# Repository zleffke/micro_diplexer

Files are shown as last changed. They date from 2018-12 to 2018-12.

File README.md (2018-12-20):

# micro_diplexer
KJ4QLP VHF/UHF Diplexer

## Credit where its due!
Inspired by the [KI0AG Micro-Duplexer](http://k0lee.com/duplexer.php) project.  I basically took this design and tweaked some of the values to modify the operating region of the diplexer.

### Note on Terminology - Diplexer vs. Duplexer
Both are three port devices.
A Diplexer is a devices that combines two separate bands (i.e VHF and UHF) into one port.  
A Duplexer is a device that combines two frequencies in the same band onto one port (like the input and output frequencies for a single band repeater).

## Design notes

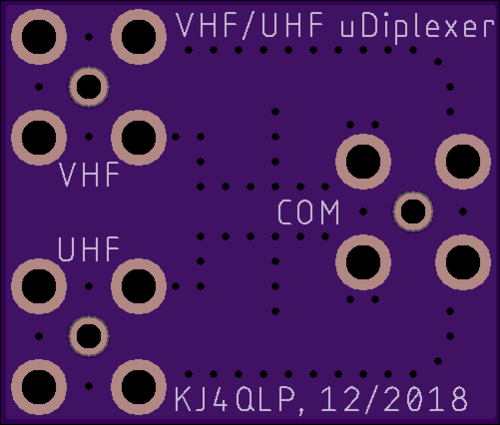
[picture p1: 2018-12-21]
eagle/ver2/rev-/osh_park_bottom.png

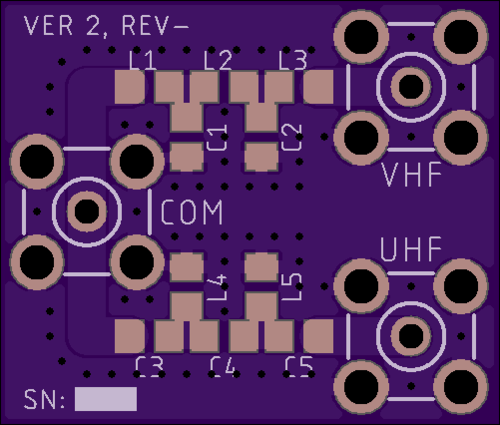
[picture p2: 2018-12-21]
eagle/ver2/rev-/osh_park_top.png

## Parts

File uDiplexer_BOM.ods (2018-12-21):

Supplier | Part # | Description | U/L | Qty | Unit Cost | Total Cost | LINK | Part Ref
Mouser | 603-CC805FRNPO9BN220 | Multilayer Ceramic Capacitors MLCC - SMD/SMT 22pF 50V NPO 1% 0805 | ea | 20 | $0.14 | $2.88 | LINK (https://www.mouser.com/ProductDetail/Yageo/CC0805FRNPO9BN220) | C1, C2
Mouser | 603-CC805CRNPO9BN4R7 | Multilayer Ceramic Capacitors MLCC - SMD/SMT 4.7pF 50V NPO .25pF | ea | 20 | $0.07 | $1.36 | LINK (https://www.mouser.com/ProductDetail/Yageo/CC0805CRNPO9BN4R7) | C3, C5
Mouser | 603-CC805CRNPO9BN3R0 | Multilayer Ceramic Capacitors MLCC - SMD/SMT 3.0pF 50V NPO .25pF | ea | 20 | $0.09 | $1.82 | LINK (https://www.mouser.com/ProductDetail/Yageo/CC0805CRNPO9BN3R0?qs=sGAEpiMZZMs0AnBnWHyRQMmNi2XLSyBh6TY5yJK9m4s%3D) | C4
Mouser | 81-LQW2BAS68NG00L | Fixed Inductors 68 NH 2% 0805 | ea | 20 | $0.23 | $4.50 | LINK (https://www.mouser.com/ProductDetail/Murata-Electronics/LQW2BAS68NG00L) | L1, L3
Mouser | 81-LQW2BASR10G00L | Fixed Inductors 100 NH 2% 0805 | ea | 20 | $0.23 | $4.50 | LINK (https://www.mouser.com/ProductDetail/Murata-Electronics/LQW2BASR10G00L) | L2
Mouser | 994-0805HP-18NXGRB | Fixed Inductors 18nH 2% 1.2A DCR=0.050Ohms | ea | 15 | $1.14 | $17.10 | LINK (https://www.mouser.com/ProductDetail/Coilcraft/0805HP-18NXGRB) | L4, L5
Mouser | 994-0805CS-150XGLC | Fixed Inductors 0805CS AEC-Q200 15 nH 2 % 0.6 A | ea | 15 | $1.17 | $17.55 | LINK (https://www.mouser.com/ProductDetail/Coilcraft/0805CS-150XGLC) | L4, L5 ; alt
Mouser | 581-08055U180FAT2A | Multilayer Ceramic Capacitors MLCC - SMD/SMT 50V 18 pF 0.01 1% Tol | ea | 20 | $0.42 | $8.30 | LINK (https://www.mouser.com/ProductDetail/AVX/08055U180FAT2A) | C1, C2 ; alt
Mouser | 603-CC805CRNPO9BN2R7 | Multilayer Ceramic Capacitors MLCC - SMD/SMT 2.7pF 50V NPO .25pF | ea | 20 | $0.07 | $1.36 | LINK (https://www.mouser.com/ProductDetail/Yageo/CC0805CRNPO9BN2R7) | C4; alt
 |  |  |  |  |  | $0.00
 |  |  |  |  | Subtotal | $59.37
NOTE: This BOM has higher quantities than necessary for a single board. This was the BOM I used to build 6 boards (ver1 and ver2 @ 3 brds each) and to have spares.
NOTE: The last three items marked as ‘alternates’ are for the original values used in the KI0AG microduplexer project. I tweaked values, but want to experiment.

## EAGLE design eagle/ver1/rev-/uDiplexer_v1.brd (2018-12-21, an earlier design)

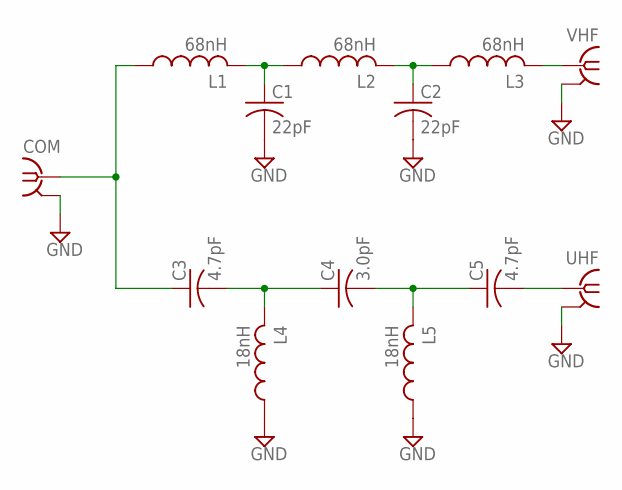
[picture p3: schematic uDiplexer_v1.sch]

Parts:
C1, C2: 22pF; C0805K
C3, C5: 4.7pF; C0805K
C4: 3.0pF; C0805K
COM: SMA-142-0711-821/826; J502-ND-142-0711-821/826
L1, L2, L3: 68nH; C0805K
L4, L5: 18nH; C0805K
UHF: SMA-142-0711-821/826; J502-ND-142-0711-821/826
VHF: SMA-142-0711-821/826; J502-ND-142-0711-821/826

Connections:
GND: C1.2, C2.2, COM.G@1 (2), COM.G@2 (2), COM.G@3 (2), COM.G@4 (2), L4.1, L5.1, UHF.G@1 (2), UHF.G@2 (2), UHF.G@3 (2), UHF.G@4 (2), VHF.G@1 (2), VHF.G@2 (2), VHF.G@3 (2), VHF.G@4 (2)
unnamed: C1.1, L1.2, L2.1
unnamed: C2.1, L2.2, L3.1
unnamed: L3.2, VHF.1
unnamed: C3.2, C4.1, L4.2
unnamed: C4.2, C5.1, L5.2
unnamed: C5.2, UHF.1
unnamed: C3.1, COM.1, L1.1

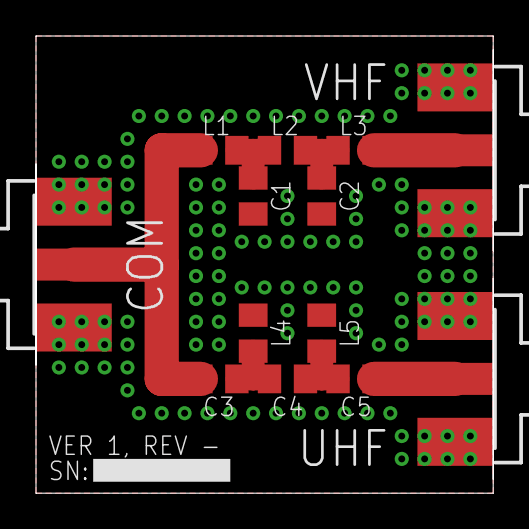
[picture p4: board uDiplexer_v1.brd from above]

Board: 2 copper layers, 25.4 x 25.4 mm, 13 parts (0 on the bottom side), 8 nets.

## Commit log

2018-12-20 initial commit of qucs schematic and simulation. updated readme.
    [ki0ag_diplexer.sch]
2018-12-21 commit of two versions, PCB SMA and Edge Launch SMA. Ordered at Osh Park.
    [uDiplexer_v1.brd, uDiplexer_v1.sch, uDiplexer_v2.brd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]
2018-12-21 adding BOM. Note the BOM has larger quantities than necessary (multiple builds, plus spares). It also has a few alternate values for experimentation.
    [uDiplexer_BOM.ods]
